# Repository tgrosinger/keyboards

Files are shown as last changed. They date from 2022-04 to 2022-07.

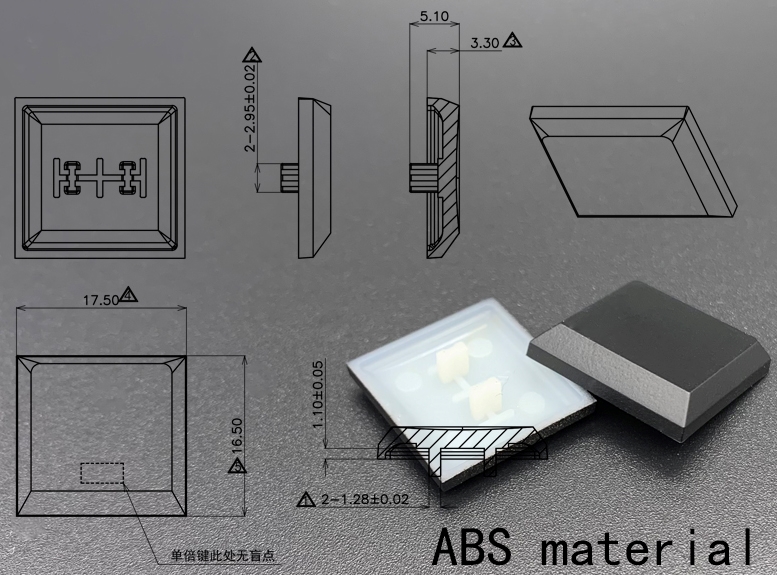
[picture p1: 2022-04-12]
chrysemys/resources/Kailh Choc Keycaps.jpg

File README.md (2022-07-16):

# Keyboards by Tony

Resources and designs for the custom keyboards I have created.

## The Keyboards

### Chrysemys

[Source Files](https://git.sr.ht/~tgrosinger/keyboards/tree/main/item/chrysemys)

A 34-key single-board keyboard created with [Ergogen](https://ergogen.xyz). Powered by a ProMicro-compatible board, such as the nice!nano.

This keyboard is my first attempt at using Ergogen, and my first custom keyboard, so it will likely be rough around the edges. I predict there will be future keyboards listed here which refine the ideas implemented in this board.

### Pseudacris

[Source Files](https://git.sr.ht/~tgrosinger/keyboards/tree/main/item/pseudacris)

A 34-key single-board keyboard created with [Ergogen](https://ergogen.xyz). Powered by an integrated MCU, derived directly from the [nRFMicro](https://github.com/joric/nrfmicro/).

This keyboard is almost identical to Chrysemys, but switches to normal Choc switches, adds hotswap, and moves the switches closer together.

### Future Keyboards

Eventually I would like to build a keyboard which has an integrated trackpoint, trackpad, or trackball. It will likely be based on Pseudacris.

## License

All files in this repository are covered by the GPLv3 license. See the [LICENSE](https://git.sr.ht/~tgrosinger/keyboards/tree/main/item/LICENSE) file for more information.

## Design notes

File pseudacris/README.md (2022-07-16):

# Pseudacris

A 34-key single-board keyboard created with [Ergogen](https://ergogen.xyz).

This keyboard is materially extremely similar to Chrysemys, with the intention to change the following:

- Change from Kailh Choc Mini to the normal Kailh Choc switches.
  - I have not been happy with how the mini switches feel to type on. They feels as though they are going to bind up too often and especially make chords more difficult.
  - This will reduce manufacturing costs because the extra cutouts needed for the mini switches requires excess milling time.
- Use hotswap sockets for the switches.
- Move the switches closer together, so there is less of a gap between key caps.
- Use an integrated MCU, based on the nRFMicro rather than a nice!nano.

## Building Firmware

The firmware for this keyboard can be found on my [ZMK fork](https://github.com/tgrosinger/zmk/tree/tgrosinger-keyboards/app/boards/arm/pseudacris). Instructions for building can be found in the readme in that directory.

If you would like to build your own key layout for this keyboard, follow the instruction for [Building from `zmk-config` folder](https://zmk.dev/docs/development/build-flash#building-from-zmk-config-folder).

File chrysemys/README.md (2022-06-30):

# Chrysemys

A 34-key single-board keyboard created with [Ergogen](https://ergogen.xyz).

## Design Goals

- Bluetooth connectivity.
- Single board, with an outward rotation between the two halves for ergonomic comfort.
- Using the ZMK firmware, as it has the best bluetooth support at the moment.
- A focus on keeping the entire keyboard as thin as possible.

## Bill of Materials

- 36 [Kailh Low-Profile Mini Choc Switches (CPG1232)](https://www.aliexpress.com/item/4000277394324.html)
  - Note: These are the "mini" swtiches, which are not compatible with the normal Choc layout.
- 1 package [Kailh Low-Profile Keycaps](https://www.aliexpress.com/item/32979973961.html)
  - Alternatively, the [MBK Choc Keycaps](https://mkultra.click/mbk-choc-keycaps)
- 1 Pro-Micro compatible microcontroller. I recommend one with Bluetooth and an integrated battery charger, such as the [nice!nano](https://nicekeyboards.com/nice-nano/).
- 1 surface mount SPDT sliding switch for the power switch. [LCSC #C128955](https://lcsc.com/product-detail/Slide-Switches_Korean-Hroparts-Elec-K3-1296S-E1_C128955.html) fits the footprint. Alternatively, you can jump the pins on the board and depend on the software standby features.
- 1 surface mount button for the reset switch. [LCSC #C2888943](https://lcsc.com/product-detail/Tactile-Switches_BZCN-TSA010A2010A02_C2888943.html) fits the footprint. This part is optional. You can also jump the reset pin on the MCU with tweezers or bind to a key in QMK.
- 1 301230 LiPo battery such as [this one](https://keyhive.xyz/shop/nicenano)
- Adhesive rubber dome feet

## Center Cover

After use, I have decided to instead place the battery under the nice!nano and omit the center cover. This does leave a hole in the middle of the keyboard, but maybe we just call it a handle.

## Firmware

- [Docs](https://zmk.dev/docs/development/build-flash#building-from-zmk-config-folder) on building firmware using the `zmk-config` from this repo.
  - Note: It still needs to be built from inside the `/app` directory in the ZMK repo.
  - `west build -b nice_nano_v2 -- -DSHIELD=chrysemys -DZMK_CONFIG="/workspaces/zmk-config/config"`

## Inspiration

### GergoPlex

The [GergoPlex](https://www.gboards.ca/product/gergoplex) is a 36 key keyboard which I purchased as a partialy assembled board. The key layout is excellent, however the thumb keys are slightly too far in towards the hands, and the split design results in my keyboard halves wandering away from me, or hard to use on uneven surfaces. I worked around some of these problems by creating a board in which the two halves are nestled in just the right orientation, however that does not help the thumb key issue.

### Hummingbird

The [Hummingbird layout](https://github.com/PJE66/hummingbird), and [Rufous, the Ergogen recreation](https://github.com/jcmkk3/trochilidae/tree/main/rufous) have been a big help in getting me started with Ergogen and building the layout I'm looking for.

## Credits

### Footprints

- Several footprints used in this project were borrowed from [jcmkk3's Trochildae collection](https://github.com/jcmkk3/trochilidae/tree/main/trochilidae.pretty)

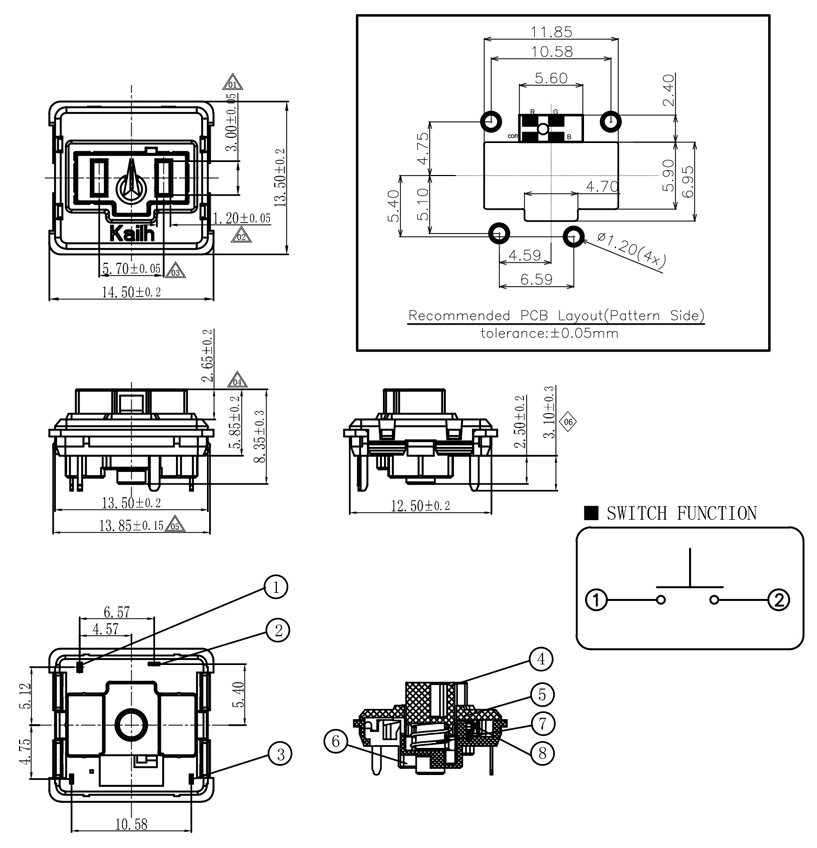
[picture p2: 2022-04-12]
chrysemys/resources/Kailh Choc Mini Drawing.jpg

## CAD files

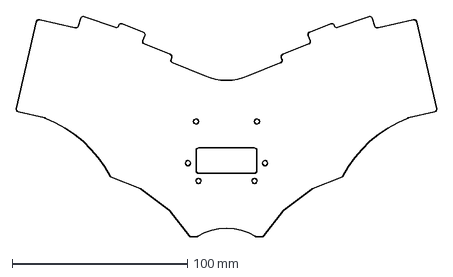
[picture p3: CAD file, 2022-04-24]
chrysemys/output/outlines/panel.dxf
240.3 x 126.0 mm

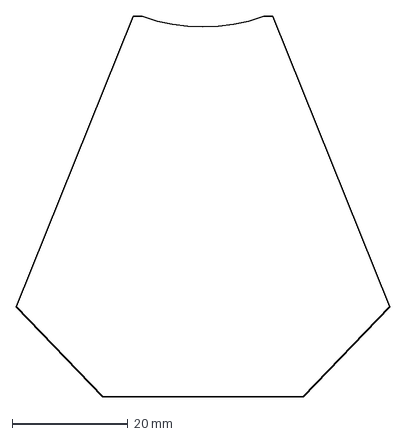
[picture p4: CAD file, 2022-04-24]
chrysemys/output/outlines/top_plate.dxf
64.4 x 65.6 mm

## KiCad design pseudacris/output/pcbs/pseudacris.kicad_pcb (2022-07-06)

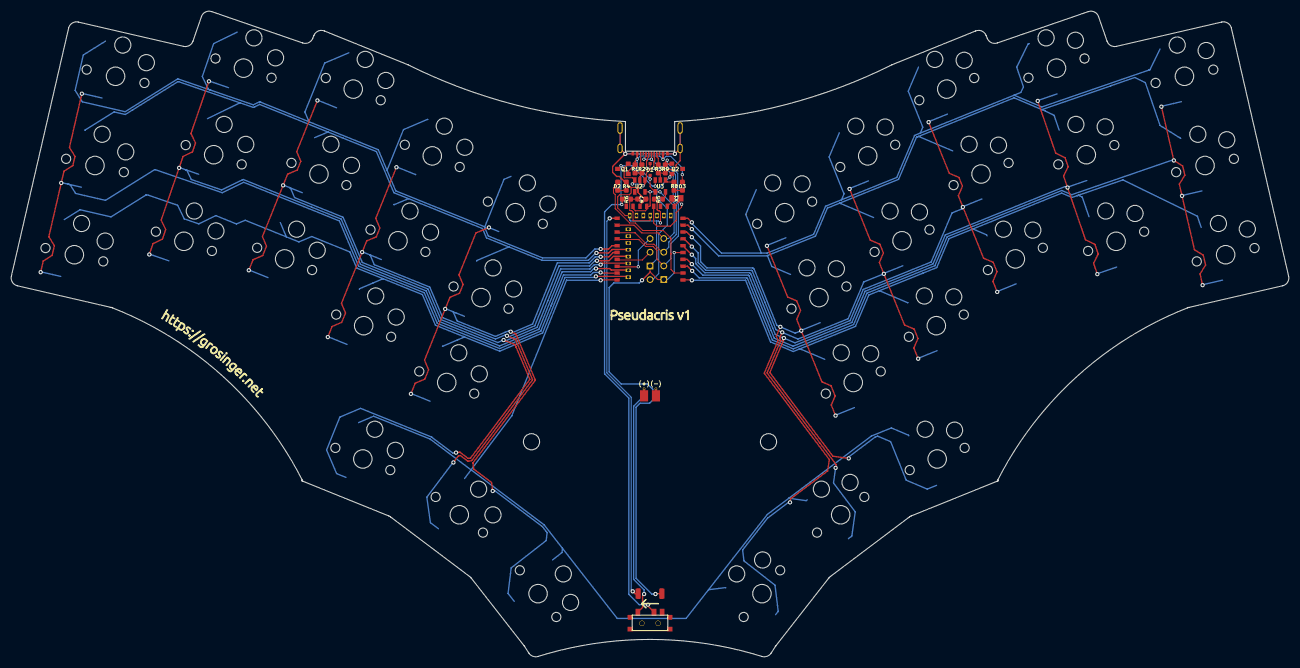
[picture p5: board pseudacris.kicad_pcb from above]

Board: 2 copper layers, 237.2 x 119.9 mm, 60 parts (0 on the bottom side), 39 nets.

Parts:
B1: Button; TwoLeadButton
BT1: Battery_Cell; BatteryPads
D1: 1N5819; D_SOD-323F
D2: BLUE; LED_0603_1608Metric
D3: RED; LED_0603_1608Metric
J1: USB-C USB 2.0 MC-372; USB-C_C168688
J2: Conn_01x04; connector_swd
J4: Conn_01x04; connector_usb
Q1, Q2: AO3407; SOT-23
R1: 100K; R_0603_1608Metric
R2, R3: 5.1K; R_0603_1608Metric
R4, R8: 1K; R_0603_1608Metric
R5: RPROG; R_0603_1608Metric
R6: 820K; R_0603_1608Metric
R7, R9: 2M; R_0603_1608Metric
S1, S2, S3, S4, S5, S6, S7, S8, S9, S10, S11, S12, S13, S14, S15, S16, S17, S18, S19, S20, S21, S22, S23, S24, S25, S26, S27, S28, S29, S30, S31, S32, S33, S34, S35, S36: PG1350
T1: SPDT_C128955
U1: E73-2G4M08S1C; E73-2G4M08S1C-52840
U2: AP2112K-3.3; SOT-23-5
U3: TP4054; SOT-23-5
X1: 32768kHz; Crystal_SMD_MicroCrystal_CM9V-T1A-2Pin_1.6x1.0mm

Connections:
/P0.00: U1.11 (P0.00/XL1), X1.2
/P0.01: U1.13 (P0.01/XL2), X1.1
/P0.02: S28.2, S29.2, S30.2, S35.2, U1.7 (P0.02/AIN0)
/P0.03: S19.2, S20.2, S21.2, U1.3 (P0.03/AIN1)
/P0.09: S1.2, S2.2, S3.2, U1.41 (P0.09/NFC1)
/P0.10: S16.1, S17.1, S18.1, S34.1, S35.1, S36.1, U1.43 (P0.10/NFC2)
/P0.13: S3.1, S6.1, S9.1, S12.1, S15.1, U1.33 (P0.13)
/P0.22: S2.1, S5.1, S8.1, S11.1, S14.1, U1.34 (P0.22)
/P0.24: S13.2, S14.2, S15.2, S18.2, U1.35 (P0.24)
/P0.28: S22.2, S23.2, S24.2, U1.4 (P0.28/AIN4)
/P0.29: S31.2, S32.2, S33.2, S36.2, U1.8 (P0.29/AIN5)
/P0.30: S21.1, S24.1, S27.1, S30.1, S33.1, U1.10 (P0.30/AIN6)
/P0.31: S20.1, S23.1, S26.1, S29.1, S32.1, U1.9 (P0.31/AIN7)
/P1.00: S10.2, S11.2, S12.2, S17.2, U1.36 (P1.00)
/P1.02: S7.2, S8.2, S9.2, S16.2, U1.38 (P1.02)
/P1.04: S4.2, S5.2, S6.2, U1.40 (P1.04)
/P1.06: S1.1, S4.1, S7.1, S10.1, S13.1, U1.42 (P1.06)
/P1.11: S19.1, S22.1, S25.1, S28.1, S31.1, U1.1 (P1.11)
/P1.13: S25.2, S26.2, S27.2, S34.2, U1.6 (P1.13)
BATT: BT1.1, T1.1
BATTERY_PIN: R6.2, R7.1, U1.18 (P0.04/AIN2)
BLUE_LED: D2.2 (A), U1.2 (P1.10)
CC1: J1.A5 (CC1), R3.1
CC2: J1.B5 (CC2), R2.1
DATA+: J1.A6 (D+), J1.B6 (D+), J4.2, U1.31 (USB_D+)
DATA-: J1.A7 (D-), J1.B7 (D-), J4.3, U1.29 (USB_D-)
GND: B1.2, BT1.2, J1.A1 (GND), J1.S1 (SHIELD), J2.2, J4.1, R1.2, R2.2, R3.2, R4.2, R5.2, R7.2, R9.2, U1.5 (GND), U1.21 (GND), U1.24 (GND), U2.2 (GND), U3.2 (VSS)
unnamed: D1.1 (K), Q1.2 (S), U2.1 (VIN), U2.3 (EN)
unnamed: D2.1 (K), R4.1
unnamed: D3.1 (K), R8.1
unnamed: R5.1, U3.5 (PROG)
unnamed: R8.2, U3.1 (STAT)
POWER_PIN: Q2.1 (G), R9.1, U1.17 (P1.09)
RESET: B1.1, U1.26 (P0.18/RESET)
SWC: J2.4, U1.39 (SWDCLK)
SWD: J2.3, U1.37 (SWDIO)
VBAT: Q1.3 (D), R6.1, T1.2, U3.3 (VBAT)
VBUS: D1.2 (A), D3.2 (A), J1.A4 (VBUS), J4.4, Q1.1 (G), R1.1, U1.27 (VBUS), U3.4 (VDD)
nRF_VDD: J2.1, Q2.2 (S), U1.19 (VDD), U1.23 (VDDH), U2.5 (VOUT)

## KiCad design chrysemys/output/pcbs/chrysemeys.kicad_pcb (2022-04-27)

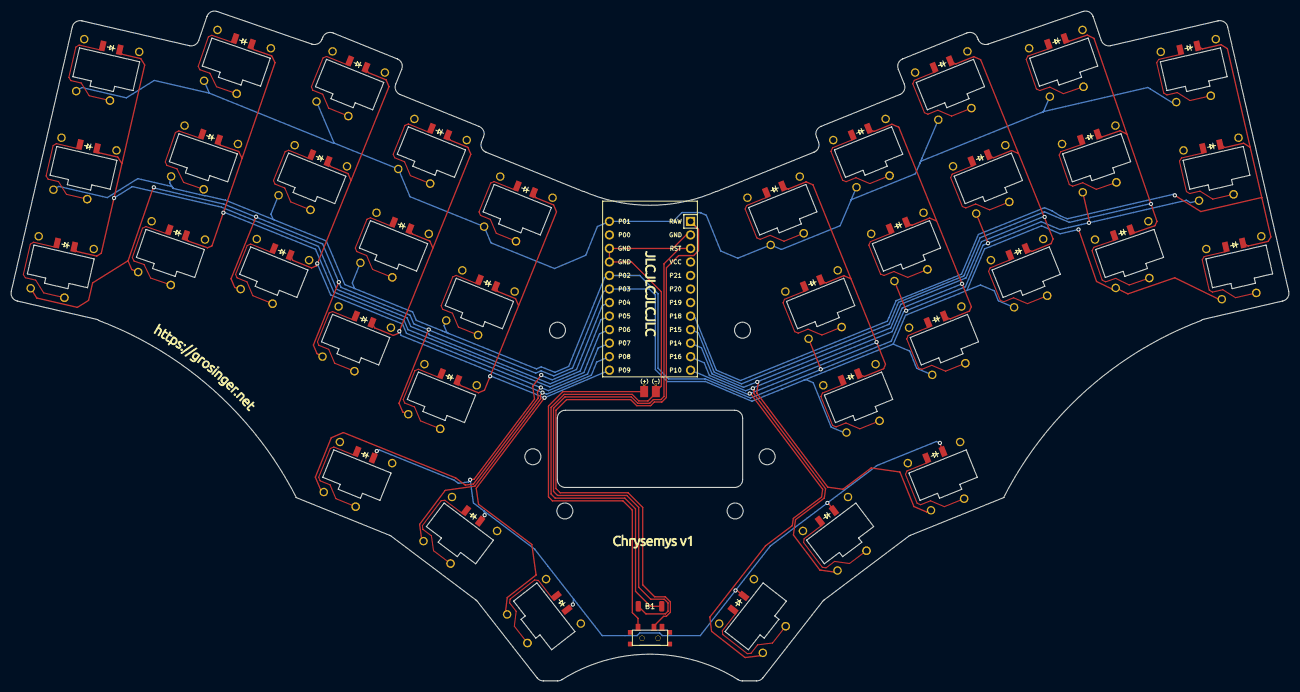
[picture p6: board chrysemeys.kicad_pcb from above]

Board: 2 copper layers, 240.0 x 125.8 mm, 40 parts (0 on the bottom side), 18 nets.

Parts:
B1: Button; TwoLeadButton
BT1: Battery_Cell; BatteryPads
MCU1: ProMicro
S1, S2, S3, S4, S5, S6, S7, S8, S9, S10, S11, S12, S13, S14, S15, S16, S17, S18, S19, S20, S21, S22, S23, S24, S25, S26, S27, S28, S29, S30, S31, S32, S33, S34, S35, S36: Kailh_PG1232
T1: SPDT_C128955

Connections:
BATT: BT1.1, T1.1
GND: B1.2, BT1.2, MCU1.2, MCU1.15, MCU1.16
P1: MCU1.13, S3.1, S6.1, S9.1, S12.1, S15.1, S21.1, S24.1, S27.1, S30.1, S33.1
P2: MCU1.17, S2.1, S5.1, S8.1, S11.1, S14.1, S20.1, S23.1, S26.1, S29.1, S32.1
P3: MCU1.18, S1.1, S4.1, S7.1, S10.1, S13.1, S19.1, S22.1, S25.1, S28.1, S31.1
P4: MCU1.19, S16.2, S17.2, S18.2, S34.2, S35.2, S36.2
P5: MCU1.20, S1.2, S2.2, S3.2
P6: MCU1.21, S4.2, S5.2, S6.2
P7: MCU1.22, S7.2, S8.2, S9.2, S16.1
P8: MCU1.23, S10.2, S11.2, S12.2, S17.1
P9: MCU1.24, S13.2, S14.2, S15.2, S18.1
P10: MCU1.12, S31.2, S32.2, S33.2, S36.1
P14: MCU1.10, S25.2, S26.2, S27.2, S34.1
P15: MCU1.9, S22.2, S23.2, S24.2
P16: MCU1.11, S28.2, S29.2, S30.2, S35.1
P18: MCU1.8, S19.2, S20.2, S21.2
RAW: MCU1.1, T1.2
RST: B1.1, MCU1.3

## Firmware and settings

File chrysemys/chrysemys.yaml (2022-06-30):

#
# NOTES:
#
# - The thumb key nets are inverted compared to rest
# - The right half column nets are in a strange order
#

units:
  cx: 18 # Keycap is 17.5mm wide
  cy: 17 # Keycap is 16.5mm tall
  kx: cx + 0.5 # Key spacing horizontal
  ky: cy + 0.5 # Key spacing vertical
  plate_padding: 2
  pinky_splay: 6
  ring_splay: 3
  angle: 22 # Angle between two halves
  mounting_hole_radius: 1.5
  mcu_height: 33
  mcu_width: 18
  batt_width: 11.5
  batt_length: 31.8
  batt_padding: 1.5
points:
  mirror:
    ref: matrix_inner_top
    distance: 50
  zones:
    matrix:
      key:
        footprints:
          chocmini:
            type: chocmini_with_diode
            nets:
              from: "=row_net"
              to: "=column_net"
      rotate: -angle + pinky_splay + ring_splay
      columns:
        pinky:
          key:
            column_net: P5
            mirror.column_net: P18
          rows:
            bottom:
              bind: [0.5ky, 1, 0, 0]
            home:
              bind: [0.5ky, 0.5kx, 0.5ky, 0]
            top:
              bind: [0, 0.5kx, 0.5ky, 0]
        ring:
          rotate: -pinky_splay
          stagger: 7
          spread: kx + 1
          key:
            column_net: P6
            mirror.column_net: P15
          rows:
            bottom:
              bind: [0.5ky, 0, 0, 5]
            home:
              bind: [0.5ky, 0.5kx, 0.5ky, 0.5kx]
            top:
              bind: [0, 0.5kx, 0.5ky, 0]
        middle:
          rotate: -ring_splay
          stagger: 3
          spread: kx + 1
          key:
            column_net: P7
            mirror.column_net: P14
          rows:
            bottom:
              bind: [0.5ky, 5, 0, 5]
            home:
              bind: [0.5ky, 0.5kx, 0.5ky, 0.5kx]
            top:
              bind: [0, 0, 0.5ky, 0]
        index:
          stagger: -6
          key:
            column_net: P8
            mirror.column_net: P16
          rows:
            bottom:
              bind: [0.5ky, 5, 0, 0]
            home:
              bind: [0.5ky, 0.5kx, 0.5ky, 0.5kx]
            top:
              bind: [0, 0, 0.5ky, 5]
        inner:
          stagger: -4
          key:
            column_net: P9
            mirror.column_net: P10
          rows:
            bottom:
              bind: [0.5ky, 2, 0, 0]
            home:
              bind: [0.5ky, 0.5kx, 0.5ky, 0.5kx]
            top:
              bind: [0, 5, 0.5ky, 5]
      rows:
        bottom:
          row_net: P3
          mirror.row_net: P3
        home:
          row_net: P2
          mirror.row_net: P2
        top:
          row_net: P1
          mirror.row_net: P1
    thumbfan:
      anchor:
        ref: matrix_inner_bottom
        shift: [-(kx/2), -(ky + 2)]
      key:
        footprints:
          chocmini:
            type: chocmini_with_diode
            nets:
              from: "=column_net"
              to: "=row_net"
      columns:
        near:
          rows:
            thumb:
              bind: [10, 5, 0, 1]
              column_net: P7
              mirror.column_net: P14
        home:
          rotate: -15
          spread: 20
          origin: [-10, -9]
          rows:
            thumb:
              bind: [5, 5, 0, 5]
              column_net: P8
              mirror.column_net: P16
        far:
          rotate: -15
          spread: 20
          origin: [-10, -9]
          rows:
            thumb:
              bind: [5, 1, 0, 5]
              column_net: P9
              mirror.column_net: P10
      rows:
        thumb:
          row_net: P4
          mirror.row_net: P4
outlines:
  exports:
    _mcu:
      - type: rectangle
        size: [mcu_width, mcu_height]
        anchor:
          ref:
            - matrix_inner_top
            - mirror_matrix_inner_top
          shift:
            - -mcu_width/2
            - -mcu_height + 1
    _battery:
      - type: rectangle
        size: [batt_length, batt_width]
        anchor:
          ref:
            - matrix_inner_top
            - mirror_matrix_inner_top
          shift:
            - -batt_length/2
            - -mcu_height - batt_width - 6 # Below the MCU and bat pads
    _battery_cutout:
      - type: rectangle
        size:
          - batt_length + 2 batt_padding
          - batt_width + 2 batt_padding
        anchor:
          ref:
            - matrix_inner_top
            - mirror_matrix_inner_top
          shift:
            - -(batt_length + 2 batt_padding)/2 # Half the width
            - -mcu_height - batt_width - 6 - batt_padding # Below the MCU and bat pads
    _key_outline:
      - type: keys
        side: both
        size: 16
    _center:
      - type: polygon
        points:
          - ref: matrix_inner_top
            shift: [cx/2, cy/2-1]
          - ref: mirror_matrix_inner_top
            shift: [cx/2, cy/2-1]
          - ref: mirror_thumbfan_home_thumb
            shift: [-cx/3, cy/2]
          - ref: mirror_thumbfan_far_thumb
            shift: [cx/2, -cy/2+0.5]
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

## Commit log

2022-04-13 Add outline for center cover plate
2022-04-16 Add footprints and nets
    Still missing the MCU and diodes.
    [chrysemys.yaml]
2022-04-18 Add diodes to switches
2022-04-19 Add pads for soldering battery connnection
2022-04-19 Add cutout for mounting battery
2022-04-19 Add mounting holes
2022-04-20 Add footprint for chocmini with diode
2022-04-21 Add footprint for mounting hole and battery pads
2022-04-21 Add reset jumper and power switch
    [chrysemys.yaml]
2022-04-24 Add new reset button footprint
2022-04-24 Initial routing of PCB
    [chrysemeys.kicad_pcb]
2022-04-24 Add output artifacts
    [panel.dxf, top_plate.dxf]
2022-04-26 Small pcb tweaks for DRC
    [chrysemeys.kicad_pcb]
2022-04-27 Add artwork
    [chrysemeys.kicad_pcb]
2022-04-27 Update Chrysemys BOM
2022-07-04 Finished updating board outline
2022-07-05 Start routing pseudacris
    [pseudacris.kicad_pcb]
2022-07-06 Refining pcb layout
    [pseudacris.kicad_pcb]
2022-07-06 Pseudacris v1 sent to manufacturer
    [pseudacris.kicad_pcb]
2022-07-16 Ignore extra kicad files
